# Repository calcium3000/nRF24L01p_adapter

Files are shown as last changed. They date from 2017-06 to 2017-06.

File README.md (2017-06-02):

# nRF24L01+ to Raspberry Pi adapter
Here lies a simple adapter for attaching one of those dirt-cheap nRF24L01+ modules to a Raspberry Pi (all models).  As seen on calcium3000.wordpress.com.

## Assembly
Pads are included for an optional 0805 surface mount capacitor, C1.  Some have reported that such a capacitor helps prevent wonkiness when transmitting at higher output (0dBm).  If extra capacitance at the power rails sounds peachy, install this guy first to make life easier later on.

Next, install P1 with a 2x4, 0.1" (2.54mm) female header such that the header sticks out of the side labeled *BOTTOM* -- this is also where the P1 designator sits.  P2 can either be another 2x4 female header for easy exchange of nRFs, or an nRF module can be soldered directly in.  Either way, make sure the header/radio protrudes from the opposite side of P1, labeled *TOP*.  If the nRF is directly soldered in, don't forget to clip the leads on the bottom side lest they sit dangerously close to the Broadcom chip and look quite ugly.

## Connection to RPi
This adapter is meant to plug directly into the GPIO header of a Raspberry Pi, facing inwards towards the processor.  Our adapter friend sits directly in the middle of the header on pins 17 to 24 (+3.3V to BCM 8) leaving 8 rows (16 pins) on each side when seated correctly.  See https://pinout.xyz for a good pin diagram.

Below is a table describing the pin functions and how they map from the RPi to the nRF24L01+.

| Pin function | nRF24L01+ | Raspberry Pi |
| --- | --- | --- |
| VDD | VDD (2) | +3.3V (17) |
| GND | GND (1) | GND (20) |
| SCK | SCK (5) | BCM 11/SCK (23)  |
| MOSI | MOSI (6)  | BCM 10/MOSI (19) |
| MISO | MISO (7)  | BCM 9/MISO (21)  |
| CSN | CSN (4) | BCM 8/CE0 (24) |
| CE | CE (3) | BCM 25 (22) |
| IRQ | IRQ (8) | BCM 24 (18) |

## License
Hardware files for this guy are licensed under the TAPR Open Hardware License.  See LICENSE.txt for more information.

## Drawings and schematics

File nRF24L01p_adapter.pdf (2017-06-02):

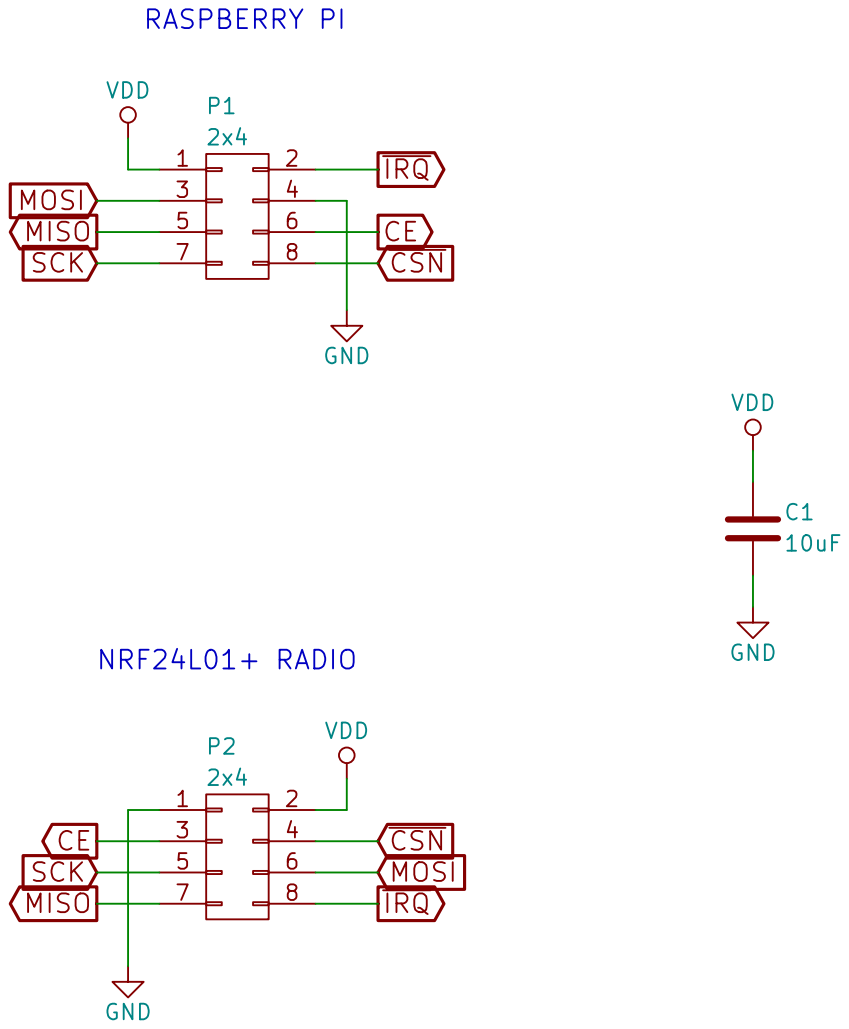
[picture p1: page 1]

Released under the TAPR Open Hardware License >> http://tapr.org/ohl.html
File: nRF24L01p_adapter.sch Sheet: / By Calvin A. Cherry >> calvincherry@gmail.com

Id: 1/1 Title: nRF24L01+ Adapter for Raspberry Pi

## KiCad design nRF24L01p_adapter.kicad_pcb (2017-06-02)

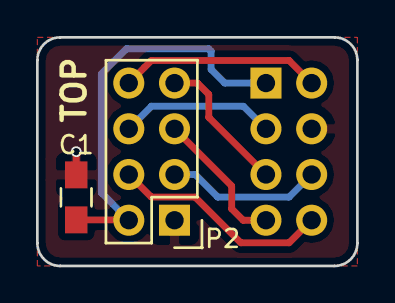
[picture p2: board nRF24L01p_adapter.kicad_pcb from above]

Board: 2 copper layers, 17.8 x 12.7 mm, 3 parts (1 on the bottom side), 8 nets.

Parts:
C1: 10uF; C_0805_HandSoldering
P1: 2x4; Socket_Strip_Straight_2x04
P2: 2x4; Socket_Strip_Straight_2x04_mirrored

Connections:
CE: P1.6, P2.3
GND: C1.2, P1.4, P2.1
MISO: P1.5, P2.7
MOSI: P1.3, P2.6
SCK: P1.7, P2.5
VDD: C1.1, P1.1, P2.2
~CSN: P1.8, P2.4
~IRQ: P1.2, P2.8
